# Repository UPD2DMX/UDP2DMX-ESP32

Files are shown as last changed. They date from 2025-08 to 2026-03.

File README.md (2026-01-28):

# 🌐 UDP2DMX Gateway (ESP32)



A lightweight and flexible UDP-to-DMX gateway based on the ESP32 platform, designed to bridge the **Loxone Home Automation System** with **DMX512-based lighting systems** via UDP over Wi-Fi.

This project enables direct communication between Loxone and DMX devices using a well-defined, lightweight UDP protocol. It is ideal for smart home installations where wireless DMX control is required.

---

## ⚙️ Key Features

- ✅ Based on the open-source [ESP-DMX library](https://github.com/someweisguy/esp_dmx)  
- ✅ UDP-based protocol (compatible with Loxone UDP protocol)  
- ✅ Easily testable via Jupyter notebook  

---

## 🚀 Getting Started

### 1. Install ESP-IDF

Make sure ESP-IDF **v5.0** is installed and properly set up. For installation instructions, refer to the [official ESP-IDF documentation](https://docs.espressif.com/projects/esp-idf/en/latest/esp32/get-started/index.html).

---

### 2. Clone the Repository

```bash
git clone "link to this Repo"
cd udp2dmx-esp32
```

---

### 3. Configure Project with `menuconfig`

Launch the ESP-IDF configuration menu:

```bash
idf.py menuconfig
```

Set the following options:

- 📶 **Component config → Wi-Fi Configuration**  
  - SSID and password for up to 3 different Wi-Fi networks
  - GPIO pin for network selection button (default: GPIO 0)

---

### 4. Advanced Configuration via REST API

After the device is running, you can configure advanced settings via the built-in REST API:

#### 📋 Configuration File Structure

The device uses a `config.json` file stored in SPIFFS with the following structure:

```json
{
    "hostname": "udp2dmx2",
    "ct_config": {
        "1": 2700,
        "2": 6500,
        "5": 3000
    },
    "default_ct": {
        "min": 3400,
        "max": 6600
    }
}
```

#### 🌐 REST API Endpoints

| Method  | Endpoint | Description |
| --- | --- | --- |
| `GET` | `/config` | Retrieve current configuration |
| `POST`  | `/config` | Replace entire configuration |
| `PATCH` | `/config/patch` | Update specific configuration values |

#### 📝 Configuration Options

- **`hostname`**: Device hostname for network identification
- **`ct_config`**: Color temperature mapping for specific channels (channel → Kelvin)
- **`default_ct`**: Default color temperature range for DMXL commands
  - `min`: Minimum color temperature in Kelvin
  - `max`: Maximum color temperature in Kelvin

#### 💡 Example Usage

```bash
# Get current configuration
curl http://192.168.1.100/config

# Update hostname
curl -X PATCH http://192.168.1.100/config/patch \
  -H "Content-Type: application/json" \
  -d '{"hostname": "my-dmx-gateway"}'

# Set color temperature for channel 3
curl -X PATCH http://192.168.1.100/config/patch \
  -H "Content-Type: application/json" \
  -d '{"ct_config": {"3": 4000}}'
```

---

### 5. Build and Flash Firmware

```bash
idf.py build
idf.py flash
idf.py spiffs-flash
```

---

### 6. Monitor Output
*Optional*

```bash
idf.py monitor
```

After flashing, the device will connect to Wi-Fi and output its IP address via serial console. Note this IP for testing.

---

## 🧪 DMX Communication Test
*Optional*

You can use the included **`testudp.ipynb`** Jupyter Notebook to send test UDP commands:

1. Open the notebook in Jupyter
2. Set the IP address of your ESP32 device
3. Send UDP packets to test DMX channels
4. Watch serial monitor logs or connected DMX lights to verify output

💡 **Tip**: The status LED (if configured) will blink to confirm incoming UDP traffic.

---

## 🏠 Loxone Integration

To use the gateway in your **Loxone Config**:

1. Use **Virtual Outputs** to send UDP commands to the ESP32's IP.
2. Format the command according to the protocol (see below).
3. Configure each DMX channel or RGB output as needed.

---

## 📡 UDP Protocol Overview

The device expects UDP packets in the following formats:

| Type  | Format | Description |
| ----- | --- | --- |
| **P** | `DMXP<ch>#<percent>#<fade>` | Set a single channel to a value from 0–100% with optional fade (converted to 0–255 internally). |
| **C** | `DMXC<ch>#<value>#<fade>` | Set a single channel (0–255) with optional fade time. |
| **R** | `DMXR<ch>#<rgb>#<fade>` | Set 3 consecutive channels for RGB values. Format: `RRRGGGBBB` (e.g., `128128128`). |
| **W** | `DMXW<ch>#<wwcw>#<fade>` | Set 2 consecutive channels for Tunable White. Format: `WWWCCC` (e.g., `200050` = WW:200, CW:50). |
| **L** | `DMXL<ch>#20<brightness><CT>#<fade>` | Set brightness and color temperature. Can be used with the Lumitech type from Loxone Format: `20BBBTTTT` (e.g., `200507000` = 50% at 7000 K). |

---

## 🔆 LED Behavior – Summary

| Condition | LED Behavior | Description |
| --- | --- | --- |
| **Connected (LAN or WiFi)**<br>**No DMX error** | **Off (constantly)** | Normal operation |
| **Not connected** (LAN & WiFi) | **Slow blinking** | 500 ms on / 500 ms off |
| **DMX error active** | **Fast blinking** | 100 ms on / 100 ms off |
| **User action**<br>(e.g. Wi-Fi switch)  | **Short blinking sequence** | `n` blinks with `delay_ms` (e.g. 2× 50 ms) |
| **Connecting to LAN** | **3 short blinks** | Signals successful LAN connection |
| **Connecting to WiFi** | **2 short blinks** | Signals successful WiFi connection |
| **Receiving DMX data** | **1 short blink** | Brief signal when DMX packet is received |

---

## 📁 Project Structure

```
main/
├── include/                     # Public header files
│   ├── dmx_manager.h           # DMX hardware abstraction
│   ├── udp_protocol.h          # UDP protocol handling
│   ├── udp_server.h            # UDP server implementation
│   └── system_config.h         # System configuration
├── src/                        # Source files
│   ├── main.c                  # Application entry point
│   ├── dmx_manager.c           # DMX management & fade engine
│   ├── udp_protocol.c          # Protocol parsing & execution
│   ├── udp_server.c            # UDP server & packet handling
│   └── system_config.c         # Configuration management
└── CMakeLists.txt              # Build configuration

components/
├── my_wifi/                    # WiFi management
├── my_led/                     # LED status indication
├── my_config/                  # Configuration (CT values, hostname)
└── config_handler/             # REST API for configuration
```

---

## 📋 Requirements

- ESP32 board (e.g., ESP32 DevKitC)
- RS485 transceiver (e.g., MAX485) I am using: MAX 13487
- DMX-compatible light or fixture
- Python + Jupyter (optional, for testing)

---

## 🙏 Credits

- [ESP-DMX Library](https://github.com/someweisguy/esp_dmx) by [@someweisguy](https://github.com/someweisguy)
- **Robert Lechner** for documenting the UDP DMX protocol

---

## 💖 Support

If this project helps you, consider buying me a coffee! ☕



---

## 📃 License

MIT License — see `LICENSE` file for details.

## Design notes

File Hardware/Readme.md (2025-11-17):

# Hardware

Kicad file for the UDP2DMX board. The hardware design is not finished.

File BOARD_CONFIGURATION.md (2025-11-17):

# ESP32-Digital-GW Board Configuration

## Übersicht

Die Pin-Konfiguration des UDP2DMX-ESP32-Projekts wird jetzt über die **Menuconfig (sdkconfig)** verwaltet und nicht über den Webserver. Dies ermöglicht die Erstellung von Board-spezifischen Konfigurationsdateien.

## Hardware-Pinzuordnung (ESP32-Digital-GW)

| Funktion | GPIO Pin | Beschreibung |
|---|---|---|
| DMX TX | GPIO 17 | RS485 DI (Data In) |
| DMX RX | GPIO 16 | RS485 RO (Receive Out) |
| DMX RTS | GPIO 18 | RS485 DE (Driver Enable) |
| Debug LED | GPIO 2 | Status-LED |

## Menuconfig Optionen

Die Hardware-Pins können über `idf.py menuconfig` unter dem Menü **Hardware Configuration** konfiguriert werden:

- **DMX TX GPIO Pin** (CONFIG_DMX_TX_GPIO) - Standard: 17
- **DMX RX GPIO Pin** (CONFIG_DMX_RX_GPIO) - Standard: 16
- **DMX RTS GPIO Pin** (CONFIG_DMX_RTS_GPIO) - Standard: 18
- **DMX UART Number** (CONFIG_DMX_UART_NUM) - Standard: 2
- **DMX Baudrate** (CONFIG_DMX_BAUDRATE) - Standard: 250000
- **WiFi Switch Button GPIO** (CONFIG_WIFI_SWITCH_BUTTON_GPIO) - Standard: 0 (deaktiviert)

## Board-spezifische sdkconfig Dateien

Für verschiedene Hardware-Boards sollten Board-spezifische sdkconfig-Dateien erstellt werden:

### Verwendung

```bash
# Standard-Build mit aktueller sdkconfig
idf.py build

# Build mit ESP32-Digital-GW Konfiguration
cp sdkconfig.esp32-digital-gw sdkconfig
idf.py build
```

### Verfügbare Board-Konfigurationen

- **sdkconfig.esp32-digital-gw** - ESP32-Digital-GW Hardware
  - DMX TX: GPIO 17
  - DMX RX: GPIO 16
  - DMX RTS: GPIO 18

## Neue Board-Konfiguration erstellen

Um eine neue Board-spezifische Konfiguration zu erstellen:

1. **Menuconfig öffnen:**
   ```bash
   idf.py menuconfig
   ```

2. **Hardware Configuration anpassen:**
   - Zu `Hardware Configuration` navigieren
   - Pins für das neue Board konfigurieren

3. **Konfiguration speichern:**
   - Speichern und Menuconfig beenden

4. **Board-Datei erstellen:**
   ```bash
   cp sdkconfig sdkconfig.<board-name>
   ```

5. **In Git einbinden:**
   ```bash
   git add sdkconfig.<board-name>
   git commit -m "Add sdkconfig for <board-name>"
   ```

## Integration in system_config.c

Die Hardware-Pin-Konfiguration wird beim Kompilieren automatisch aus der sdkconfig eingebunden:

```c
#include "sdkconfig.h"

static system_config_t default_config = {
    .hardware = {
        .dmx_tx_pin = CONFIG_DMX_TX_GPIO,      // Aus sdkconfig.h
        .dmx_rx_pin = CONFIG_DMX_RX_GPIO,      // Aus sdkconfig.h
        .dmx_en_pin = CONFIG_DMX_RTS_GPIO,     // Aus sdkconfig.h
        .debug_led_gpio = 2},
    // ... weitere Konfiguration ...
};
```

## Wichtige Hinweise

- ⚠️ **Keine Web-UI Konfiguration für Pins**: Die Pins werden nicht über den Webserver konfiguriert, sondern nur über Menuconfig
- ✅ **Zur Compile-Zeit festgelegt**: Die Pin-Konfiguration wird während des Compilierens festgelegt
- ✅ **Board-Portabilität**: Board-spezifische sdkconfig-Dateien ermöglichen einfaches Wechseln zwischen verschiedenen Hardware-Konfigurationen

## Webserver-Konfiguration

Der Webserver (`http://192.168.4.1` oder `http://udp2dmx.local` `http://[hostname].local`) verwaltet weiterhin:
- WiFi-Einstellungen (Netzwerkname und Passwort)
- Netzwerk-Konfiguration (IP, DHCP, DNS)
- DMX-Inhalte (via UDP-Protokoll)

Die Hardware-Pins werden **nicht** über den Webserver konfiguriert.

## Debugging

Die aktuelle Hardware-Konfiguration kann in den Logs überprüft werden:

```bash
idf.py monitor
```

Die Logs zeigen die konfigurierten Pins beim Start an.

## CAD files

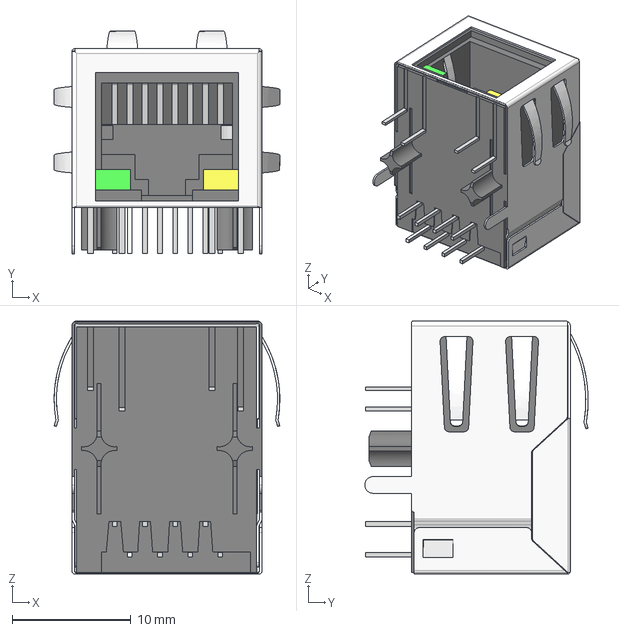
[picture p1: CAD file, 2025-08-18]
Hardware/3D/J1B1211CCD.stp
19.0 x 18.8 x 21.3 mm

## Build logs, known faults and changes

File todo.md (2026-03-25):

Webserver (manuelle Änderung der Rest API endpunkte)

- [x] lumitec testen mit Refactored code

- Menuconfig anpassen falls sinnvoll:
  - [x] DMX config 
  - [x] LED config
  - [x] Button Config
  - [x] Wifi

- [x] Webserver zur Konfiguration
- [x] Pins/RS485 Chip config über menuconfig

- [] Was ist mit den Ethernet LEDs? 

- [] OTA
- [] RS485 -2 

Muss getestet werden: 
- []Ethernet
- [x]RS485 - 1 für DMX

- github seite auf Webpage
- status auf webpage? Letzten 5 Befehle oder so fürs debugging?

# Platine
- Benötigt die Platine eine Power LED die Dauerhaft an ist? 
  - Eventuell nur einschalten wenn Knopf gedrückt? 
  - Ansonsten dunklerer LED auch in Ordnung. 

- Ethernet
  - Via USB Spannungsversorgung evtl. nicht ganz ausreichend. USB muss neu Verbunden werden damit eine sichere Netzwerkverbindung hergestellt werden kann.

- Status LED ist leicht an beim flashen. Eventuell Diode ergänzen. 
- Reset Button notwendig? 
- UART Pins auf dem Board zum flashen ohne USB? Ist USB notwendig? 

# PinOut ESP
ESP32 Wroom 32UE - 4 Mb flash
- Status LED
  - 5
- BTN0
  - 16
- RS485 - ADM 3485JRZ
  - 1
    - DI (TX): 33
    - RO (RX): 32
    - RE/DE: 13
  - 2
    - DI (TX): 12
    - RO (RX): 14
    - RE/DE: 15

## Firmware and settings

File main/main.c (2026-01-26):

#include <string.h>
#include <stdlib.h>
#include <stdio.h>
#include <math.h>

#include "freertos/FreeRTOS.h"
#include "freertos/task.h"
#include "freertos/semphr.h"
#include "esp_log.h"
#include "esp_event.h"
#include "nvs_flash.h"
#include "esp_netif.h"
// #include "protocol_examples_common.h"
#include "lwip/sockets.h"
#include "esp_dmx.h"
#include "driver/gpio.h"

#include "my_wifi.h"
#include "my_led.h"
#include "my_config.h"
#include "config_handler.h"
#include "system_config.h"

#ifdef CONFIG_ENABLE_ETHERNET
#include "my_ethernet.h"
#endif

#define DMX_UNIVERSE_SIZE DMX_PACKET_SIZE
#define UDP_PORT 6454
#define FADE_INTERVAL_MS 10
#define MAX_UDP_BUFFER_SIZE 1024

// Command result types for better error handling
typedef enum
{
    CMD_SUCCESS,
    CMD_ERROR_INVALID_CHANNEL,
    CMD_ERROR_INVALID_VALUE,
    CMD_ERROR_CONFIG_MISSING,
    CMD_ERROR_MEMORY
} command_result_t;

static const char *TAG = "udp_dmx";
static uint8_t dmx_data[DMX_UNIVERSE_SIZE] = {};
static dmx_port_t dmx_num = DMX_NUM_1;
static SemaphoreHandle_t dmx_mutex = NULL;

typedef struct
{
    bool active;
    int start_value;
    int target_value;
    int duration_ms;
    TickType_t start_time;
} fade_state_t;

static fade_state_t fade_states[DMX_UNIVERSE_SIZE] = {};

// Bounds checking function for channel validation
static bool is_channel_valid(int ch, int count)
{
    return (ch >= 1 && ch <= DMX_UNIVERSE_SIZE - count);
}

// Safe bounds checking for array access
static bool is_array_index_valid(int index)
{
    return (index >= 0 && index < DMX_UNIVERSE_SIZE);
}

// Convert speed_S to milliseconds (Using Loxone protocol)
static int speed_to_ms(int speed)
{
    if (speed == 255)
        return 0;
    if (speed >= 1 && speed <= 98)
        return speed * 591;
    if (speed >= 101 && speed <= 104)
        return (speed - 100) * 146 + 1;
    if (speed >= 201 && speed <= 254)
        return (speed - 200) * 72;
    if (speed == 254)
        return 3691;
    return 0;
}

static void stop_fade(int ch)
{
    if (!is_array_index_valid(ch))
    {
        ESP_LOGW(TAG, "Invalid channel for stop_fade: %d", ch);
        return;
    }

    if (xSemaphoreTake(dmx_mutex, pdMS_TO_TICKS(100)) == pdTRUE)
    {
        fade_states[ch].active = false;
        xSemaphoreGive(dmx_mutex);
    }
    else
    {
        ESP_LOGW(TAG, "Failed to acquire mutex in stop_fade");
    }
}

static void start_fade(int ch, int value, int duration_ms)
{
    if (!is_array_index_valid(ch))
    {
        ESP_LOGW(TAG, "Invalid channel for start_fade: %d", ch);
        return;
    }

    // Clamp value to valid range
    value = (value < 0) ? 0 : (value > 255) ? 255
                                            : value;

    if (xSemaphoreTake(dmx_mutex, pdMS_TO_TICKS(100)) == pdTRUE)
    {
        fade_states[ch].start_value = dmx_data[ch];
        fade_states[ch].target_value = value;
        fade_states[ch].duration_ms = duration_ms;
        fade_states[ch].start_time = xTaskGetTickCount();
        fade_states[ch].active = true;
        xSemaphoreGive(dmx_mutex);
    }
    else
    {
        ESP_LOGW(TAG, "Failed to acquire mutex in start_fade");
    }
}

static void fade_task(void *arg)
{
    while (1)
    {
        TickType_t now = xTaskGetTickCount();
        bool updated = false;

        if (xSemaphoreTake(dmx_mutex, pdMS_TO_TICKS(100)) == pdTRUE)
        {
            for (int ch = 0; ch < DMX_UNIVERSE_SIZE; ++ch)
            {
                if (!fade_states[ch].active)
                    continue;

                int elapsed = (now - fade_states[ch].start_time) * portTICK_PERIOD_MS;
                int duration = fade_states[ch].duration_ms;

                if (duration <= 0)
                {
                    dmx_data[ch] = fade_states[ch].target_value;
                    fade_states[ch].active = false; // Use direct access since we have mutex
                    updated = true;
                    continue;
                }

                int start = fade_states[ch].start_value;
                int target = fade_states[ch].target_value;

                uint8_t new_value;

                if (elapsed >= duration)
                {
                    new_value = target;
                    fade_states[ch].active = false; // Use direct access since we have mutex
                }
                else
                {
                    float t = (float)elapsed / (float)duration;
                    float interpolated = start + (target - start) * t;
                    new_value = (uint8_t)roundf(interpolated);
                }

                if (dmx_data[ch] != new_value)
                {
                    dmx_data[ch] = new_value;
                    updated = true;
                }
            }

            if (updated)
            {
                esp_err_t err = dmx_write(dmx_num, dmx_data, DMX_UNIVERSE_SIZE);
                if (err != ESP_OK)
                {
                    ESP_LOGW(TAG, "DMX write failed: %s", esp_err_to_name(err));
                }
            }

            xSemaphoreGive(dmx_mutex);
        }
        else
        {
            ESP_LOGW(TAG, "Failed to acquire mutex in fade_task");
        }

        vTaskDelay(pdMS_TO_TICKS(FADE_INTERVAL_MS));
    }
}

static command_result_t set_channel(int ch, int value, int fade_ms)
{
    if (!is_channel_valid(ch, 1))
    {
        ESP_LOGW(TAG, "Invalid channel: %d", ch);
        return CMD_ERROR_INVALID_CHANNEL;
    }

    // Clamp value to valid range
    value = (value < 0) ? 0 : (value > 255) ? 255
                                            : value;

    if (fade_ms > 0 && dmx_data[ch] != value)
    {
        start_fade(ch, value, fade_ms);
    }
    else
    {
        stop_fade(ch);
        if (xSemaphoreTake(dmx_mutex, pdMS_TO_TICKS(100)) == pdTRUE)
        {
            dmx_data[ch] = value;
            esp_err_t err = dmx_write(dmx_num, dmx_data, DMX_UNIVERSE_SIZE);
            if (err != ESP_OK)
            {
                ESP_LOGW(TAG, "DMX write failed: %s", esp_err_to_name(err));
            }
            xSemaphoreGive(dmx_mutex);
        }
        else
        {
            ESP_LOGW(TAG, "Failed to acquire mutex in set_channel");
            return CMD_ERROR_MEMORY;
        }
    }
    return CMD_SUCCESS;
}

static command_result_t set_multi_channels(int ch, int *values, int count, int fade_ms)
{
    if (!is_channel_valid(ch, count))
    {
        ESP_LOGW(TAG, "Invalid channel range: %d-%d", ch, ch + count - 1);
        return CMD_ERROR_INVALID_CHANNEL;
    }

    if (!values)
    {
        ESP_LOGW(TAG, "NULL values pointer in set_multi_channels");
        return CMD_ERROR_INVALID_VALUE;
    }

    if (fade_ms > 0)
    {
        for (int i = 0; i < count; ++i)
        {
            // Clamp values to valid range
            int clamped_value = (values[i] < 0) ? 0 : (values[i] > 255) ? 255
                                                                        : values[i];
            start_fade(ch + i, clamped_value, fade_ms);
        }
    }
    else
    {
        if (xSemaphoreTake(dmx_mutex, pdMS_TO_TICKS(100)) == pdTRUE)
        {
            for (int i = 0; i < count; ++i)
            {
                fade_states[ch + i].active = false; // Direct access since we have mutex
                // Clamp values to valid range
                int clamped_value = (values[i] < 0) ? 0 : (values[i] > 255) ? 255
                                                                            : values[i];
                dmx_data[ch + i] = clamped_value;
            }
            esp_err_t err = dmx_write(dmx_num, dmx_data, DMX_UNIVERSE_SIZE);
            if (err != ESP_OK)
            {
                ESP_LOGW(TAG, "DMX write failed: %s", esp_err_to_name(err));
            }
            xSemaphoreGive(dmx_mutex);
        }
        else
        {
            ESP_LOGW(TAG, "Failed to acquire mutex in set_multi_channels");
            return CMD_ERROR_MEMORY;
        }
    }
    return CMD_SUCCESS;
}
// Command parsing with validation
typedef struct
{
    char mode;
    int channel;
    int value;
    int speed;
    bool valid;
} parsed_command_t;

static parsed_command_t parse_udp_command(const char *cmd)
{
    parsed_command_t result = {0};

    if (!cmd || strlen(cmd) < 4)
    {
        ESP_LOGW(TAG, "Command too short or NULL");
        return result;
    }

    if (strncmp(cmd, "DMX", 3) != 0)
    {
        ESP_LOGW(TAG, "Command doesn't start with DMX");
        return result;
    }

    char *copy = strdup(cmd);
    if (!copy)
    {
        ESP_LOGE(TAG, "Memory allocation failed");
        return result;
    }

    char *type = strtok(copy + 3, "#");
    char *arg1 = strtok(NULL, "#");
    char *arg2 = strtok(NULL, "#");

    if (!type || !arg1)
    {
        ESP_LOGW(TAG, "Missing required arguments in command: %s", cmd);
        free(copy);
        return result;
    }

    result.mode = type[0];
    result.channel = atoi(type + 1);
    result.value = atoi(arg1);
    result.speed = arg2 ? atoi(arg2) : 255;
    result.valid = true;

    free(copy);
    return result;
}

static command_result_t handle_udp_command(const char *cmd)
{
    static command_result_t handle_udp_command(const char *cmd)
    {
        parsed_command_t parsed = parse_udp_command(cmd);

        if (!parsed.valid)
        {
            return CMD_ERROR_INVALID_VALUE;
        }

        int ch = parsed.channel;
        int val = parsed.value;
        int fade_ms = speed_to_ms(parsed.speed);
        char mode = parsed.mode;

        // Basic channel validation for commands that need multiple channels
        if ((mode == 'L' || mode == 'W') && !is_channel_valid(ch, 2))
        {
            ESP_LOGW(TAG, "Invalid channel for %c command: %d", mode, ch);
            return CMD_ERROR_INVALID_CHANNEL;
        }
        if (mode == 'R' && !is_channel_valid(ch, 3))
        {
            ESP_LOGW(TAG, "Invalid channel for RGB command: %d", ch);
            return CMD_ERROR_INVALID_CHANNEL;
        }
        if ((mode == 'C' || mode == 'P') && !is_channel_valid(ch, 1))
        {
            ESP_LOGW(TAG, "Invalid channel for %c command: %d", mode, ch);
            return CMD_ERROR_INVALID_CHANNEL;
        }

        command_result_t result = CMD_SUCCESS;

        switch (mode)
        {
        case 'R':
        {
            // Validate RGB values are in reasonable range
            if (val < 0 || val > 999999999)
            {
                ESP_LOGW(TAG, "RGB value out of range: %d", val);
                return CMD_ERROR_INVALID_VALUE;
            }

            int r = (val % 1000);
            int g = ((val / 1000) % 1000);
            int b = ((val / 1000000) % 1000);

            // Clamp RGB values to 0-255 range
            r = (r > 255) ? 255 : r;
            g = (g > 255) ? 255 : g;
            b = (b > 255) ? 255 : b;

            int rgb[3] = {r, g, b};
            result = set_multi_channels(ch, rgb, 3, fade_ms);

            if (result == CMD_SUCCESS)
            {
                ESP_LOGI(TAG, "RGB %d: R=%d G=%d B=%d mit Fading %d ms", ch, r, g, b, fade_ms);
            }
            break;
        }
        case 'W':
        {
            int ww = (val / 1000) % 1000;
            int cw = val % 1000;

            ww = ww > 255 ? 255 : (ww < 0 ? 0 : ww);
            cw = cw > 255 ? 255 : (cw < 0 ? 0 : cw);

            int tw[2] = {ww, cw};
            result = set_multi_channels(ch, tw, 2, fade_ms);

            if (result == CMD_SUCCESS)
            {
                ESP_LOGI(TAG, "TW %d: WW=%d CW=%d with fading %d ms", ch, ww, cw, fade_ms);
            }
            break;
        }
        case 'L':
        {
            if (val < 200000000 || val > 209999999)
            {
                ESP_LOGW(TAG, "Invalid Lumitec-Command: %d", val);
                return CMD_ERROR_INVALID_VALUE;
            }

            // 1) Extract target brightness (0–100) and target CT (e.g. 2700…6500)
            int brightness = (val / 10000) % 1000;
            int color_temp = val % 10000;

            brightness = brightness < 0 ? 0 : (brightness > 100 ? 100 : brightness);

            // 2) Sort WW/CW by actual CT
            int ct_ww, ct_cw, ch_ww, ch_cw;
            get_ct_sorted(ch, &ct_ww, &ct_cw, &ch_ww, &ch_cw);

            // 3) Soll-CT auf erlaubten Bereich clampen
            if (color_temp < ct_ww)
                color_temp = ct_ww;
            if (color_temp > ct_cw)
                color_temp = ct_cw;

            // 4) Decision: which channel gets how much?
            int val_ww = 0, val_cw = 0;
            int value = brightness * 255 / 100;

            if (color_temp <= ct_ww + 100)
            {
                // fast ganz warm → nur WW an
                val_ww = value;
                val_cw = 0;
            }
            else if (color_temp >= ct_cw - 100)
            {
                // fast ganz kalt → nur CW an
                val_ww = 0;
                val_cw = value;
            }
            else
            {
                // Mischfarbe → normal berechnen
                int range = ct_cw - ct_ww;
                if (range <= 0)
                {
                    ESP_LOGW(TAG, "Invalid CT range for channel %d", ch);
                    return CMD_ERROR_CONFIG_MISSING;
                }

                long num_cw = (long)brightness * (color_temp - ct_ww) * 255;
                long num_ww = (long)brightness * (ct_cw - color_temp) * 255;
                long den = (long)range * 100;

                val_cw = (int)((num_cw + den / 2) / den);
                val_ww = (int)((num_ww + den / 2) / den);

                if (val_cw * 100 / 255 < 2)
                    val_cw = 0;
                if (val_ww * 100 / 255 < 2)
                    val_ww = 0;
            }

            // 5) Array für set_multi_channels aufbauen
            int start_ch = (ch_ww < ch_cw ? ch_ww : ch_cw);
            int values[2] = {0, 0};
            values[ch_ww - start_ch] = val_ww;
            values[ch_cw - start_ch] = val_cw;

            // 6) abschicken
            result = set_multi_channels(start_ch, values, 2, fade_ms);

            if (result == CMD_SUCCESS)
            {
                ESP_LOGI(TAG, "Lichtfarbe %dK, Helligkeit %d%% → WW=%d (CH%d), CW=%d (CH%d)",
                         color_temp, brightness, val_ww, ch_ww, val_cw, ch_cw);
            }
            break;
        }

        case 'P':
            val = (val * 255) / 100;
            // Clamp percentage to valid range
            val = (val < 0) ? 0 : (val > 255) ? 255
                                              : val;
            __attribute__((fallthrough));
        case 'C':
            result = set_channel(ch, val, fade_ms);
            if (result == CMD_SUCCESS)
            {
                ESP_LOGI(TAG, "Channel %d set to %d", ch, val);
            }
            break;
        default:
            ESP_LOGW(TAG, "Unbekannter Modus: %c", mode);
            return CMD_ERROR_INVALID_VALUE;
        }

        return result;
    }
}

void udp_server_task(void *arg)
{
    int sock = socket(AF_INET, SOCK_DGRAM, IPPROTO_IP);
    if (sock < 0)
    {
        ESP_LOGE(TAG, "UDP socket creation failed: errno %d", errno);
        vTaskDelete(NULL);
        return;
    }

    struct sockaddr_in bind_addr = {
        .sin_family = AF_INET,
        .sin_port = htons(UDP_PORT),
        .sin_addr.s_addr = htonl(INADDR_ANY)};

    if (bind(sock, (struct sockaddr *)&bind_addr, sizeof(bind_addr)) < 0)
    {
        ESP_LOGE(TAG, "UDP socket bind failed: errno %d", errno);
        close(sock);
        vTaskDelete(NULL);
        return;
    }

    char rx_buffer[MAX_UDP_BUFFER_SIZE];
    struct sockaddr_in6 source_addr;
    socklen_t socklen = sizeof(source_addr);

    ESP_LOGI(TAG, "UDP server started on port %d", UDP_PORT);

    while (1)
    {
        int len = recvfrom(sock, rx_buffer, sizeof(rx_buffer) - 1, 0,
                           (struct sockaddr *)&source_addr, &socklen);

        if (len < 0)
        {
            ESP_LOGW(TAG, "UDP recvfrom failed: errno %d", errno);
            continue;
        }

        ESP_LOGD(TAG, "UDP empfangen, Länge = %d", len);

        if (len == DMX_UNIVERSE_SIZE)
        {
            // Full DMX universe data
            if (xSemaphoreTake(dmx_mutex, pdMS_TO_TICKS(100)) == pdTRUE)
            {
                memcpy(dmx_data, rx_buffer, DMX_UNIVERSE_SIZE);
                for (int i = 0; i < DMX_UNIVERSE_SIZE; ++i)
                    fade_states[i].active = false;

                esp_err_t err = dmx_write(dmx_num, dmx_data, DMX_UNIVERSE_SIZE);
                if (err != ESP_OK)
                {
                    ESP_LOGW(TAG, "DMX write failed: %s", esp_err_to_name(err));
                }
                xSemaphoreGive(dmx_mutex);
            }
            else
            {
                ESP_LOGW(TAG, "Failed to acquire mutex for DMX universe update");
            }
        }
        else if (len > 4 && len < MAX_UDP_BUFFER_SIZE && strncmp(rx_buffer, "DMX", 3) == 0)
        {
            rx_buffer[len] = '\0';
            ESP_LOGI(TAG, "DMX-Befehl empfangen: \"%s\"", rx_buffer);
            my_led_blink(1, 20);

            command_result_t result = handle_udp_command(rx_buffer);
            if (result != CMD_SUCCESS)
            {
                ESP_LOGW(TAG, "Command execution failed with result: %d", result);
            }
        }
        else
        {
            ESP_LOGW(TAG, "Invalid UDP packet received, length: %d", len);
        }
    }

    close(sock);
}

void app_main()
{
    esp_log_level_set("wifi", ESP_LOG_DEBUG);
    esp_log_level_set("event", ESP_LOG_DEBUG);
    ESP_ERROR_CHECK(nvs_flash_init());
    ESP_ERROR_CHECK(esp_netif_init());
    ESP_ERROR_CHECK(esp_event_loop_create_default());

    // Initialize mutex for thread-safe DMX operations
    dmx_mutex = xSemaphoreCreateMutex();
    if (dmx_mutex == NULL)
    {
        ESP_LOGE(TAG, "Failed to create DMX mutex");
        return;
    }

    // Initialize system configuration
    esp_err_t err = system_config_init();
    if (err != ESP_OK)
    {
        ESP_LOGE(TAG, "Failed to initialize system config: %s", esp_err_to_name(err));
        return;
    }

    const system_config_t *sys_config = system_config_get();
    system_config_print(sys_config);

    my_led_init(sys_config->hardware.debug_led_gpio);

    // Network initialization - prefer Ethernet over WiFi
    bool network_ready = false;

#ifdef CONFIG_ENABLE_ETHERNET
    if (sys_config->ethernet.enable)
    {
        ESP_LOGI(TAG, "Initializing Ethernet...");
        err = my_ethernet_init(
            sys_config->ethernet.mdc_gpio,
            sys_config->ethernet.mdio_gpio,
            sys_config->ethernet.phy_addr,
            sys_config->ethernet.phy_power_gpio,
            sys_config->ethernet.phy_rst_gpio,
            sys_config->ethernet.clock_mode,
            "udp2dmx-eth");

        if (err == ESP_OK)
        {
            err = my_ethernet_start();
            if (err == ESP_OK)
            {
                ESP_LOGI(TAG, "Ethernet started successfully");
                // Wait a bit for Ethernet to connect
                vTaskDelay(pdMS_TO_TICKS(3000));
                
                if (my_ethernet_is_connected())
                {
                    char ip_str[16];
                    if (my_ethernet_get_ip(ip_str))
                    {
                        ESP_LOGI(TAG, "Ethernet connected with IP: %s", ip_str);
                        network_ready = true;
                    }
                }
                else
                {
                    ESP_LOGW(TAG, "Ethernet link not established; will fall back to WiFi");
                }
            }
            else
            {
                ESP_LOGW(TAG, "Failed to start Ethernet: %s", esp_err_to_name(err));
            }
        }
        else
        {
            ESP_LOGW(TAG, "Failed to initialize Ethernet: %s", esp_err_to_name(err));
        }
    }
#endif

    // Start WiFi only if Ethernet is not connected
    if (!network_ready)
    {
        ESP_LOGI(TAG, "Starting WiFi (Ethernet not connected)...");
        my_wifi_init();
        network_ready = true;
    }
    else
    {
        ESP_LOGI(TAG, "Ethernet active - WiFi skipped");
    }

    // DMX Setup
    dmx_config_t config = DMX_CONFIG_DEFAULT;
    err = dmx_driver_install(dmx_num, &config, NULL, 0);
    if (err != ESP_OK)
    {
        ESP_LOGE(TAG, "DMX driver install failed: %s", esp_err_to_name(err));
        return;
    }

    err = dmx_set_pin(dmx_num, sys_config->hardware.dmx_tx_pin, sys_config->hardware.dmx_rx_pin, sys_config->hardware.dmx_en_pin);
    if (err != ESP_OK)
    {
        ESP_LOGE(TAG, "DMX pin setup failed: %s", esp_err_to_name(err));
        return;
    }

    memset(dmx_data, 0, sizeof(dmx_data));
    err = dmx_write(dmx_num, dmx_data, DMX_UNIVERSE_SIZE);
    if (err != ESP_OK)
    {
        ESP_LOGW(TAG, "Initial DMX write failed: %s", esp_err_to_name(err));
    }

    // Tasks starten
    BaseType_t task_result;
    task_result = xTaskCreate(udp_server_task, "udp_server", 8192, NULL, 5, NULL);
    if (task_result != pdPASS)
    {
        ESP_LOGE(TAG, "Failed to create UDP server task");
        return;
    }

    task_result = xTaskCreate(fade_task, "fade_task", 4096, NULL, 5, NULL);
    if (task_result != pdPASS)
    {
        ESP_LOGE(TAG, "Failed to create fade task");
        return;
    }

    ESP_LOGI(TAG, "System bereit: DMX aktiv & WiFi verbunden");
    my_led_blink(2, 200);

    spiffs_init();
    config_load_from_spiffs("/spiffs/config.json");
    start_rest_server();

    TickType_t last = xTaskGetTickCount();
    while (1)
    {
        err = dmx_send(dmx_num);
        if (err != ESP_OK)
        {
            ESP_LOGW(TAG, "DMX send failed: %s", esp_err_to_name(err));
        }
        vTaskDelayUntil(&last, pdMS_TO_TICKS(30));
    }
}

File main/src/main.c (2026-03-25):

#include <string.h>
#include <stdlib.h>
#include <stdio.h>

#include "esp_log.h"
#include "esp_event.h"
#include "nvs_flash.h"
#include "esp_netif.h"

// System modules
#include "system_config.h"
#include "dmx_manager.h"
#include "udp_server.h"
#include "udp_protocol.h"

// Component modules
#include "my_wifi.h"
#include "my_led.h"
#include "my_config.h"
#include "config_handler.h"

#ifdef CONFIG_ENABLE_ETHERNET
#include "my_ethernet.h"
#endif

static const char *TAG = "main";

// System initialization functions
static esp_err_t init_system_base(void);
static esp_err_t init_system_components(void);
static esp_err_t init_dmx_system(void);
static esp_err_t init_network_services(void);
static esp_err_t start_main_loop(void);

void app_main()
{
    ESP_LOGI(TAG, "=== UDP2DMX Gateway Starting ===");

    // Initialize system base
    esp_err_t err = init_system_base();
    if (err != ESP_OK) {
        ESP_LOGE(TAG, "Failed to initialize system base: %s", esp_err_to_name(err));
        return;
    }

    // Initialize system components
    err = init_system_components();
    if (err != ESP_OK) {
        ESP_LOGE(TAG, "Failed to initialize system components: %s", esp_err_to_name(err));
        return;
    }

    // Initialize network services first (like in working version)
    err = init_network_services();
    if (err != ESP_OK) {
        ESP_LOGE(TAG, "Failed to initialize network services: %s", esp_err_to_name(err));
        return;
    }

    // Initialize DMX system AFTER WiFi (like in working version)
    err = init_dmx_system();
    if (err != ESP_OK) {
        ESP_LOGE(TAG, "Failed to initialize DMX system: %s", esp_err_to_name(err));
        return;
    }

    ESP_LOGI(TAG, "=== System initialization complete ===");
    
    // Start main loop
    start_main_loop();
}

static esp_err_t init_system_base(void)
{
    ESP_LOGI(TAG, "Initializing system base...");

    // Set log levels
    esp_log_level_set("wifi", ESP_LOG_DEBUG);
    esp_log_level_set("event", ESP_LOG_DEBUG);

    // Initialize NVS
    esp_err_t err = nvs_flash_init();
    if (err != ESP_OK) {
        ESP_LOGE(TAG, "NVS flash init failed: %s", esp_err_to_name(err));
        return err;
    }

    // Initialize network interface
    err = esp_netif_init();
    if (err != ESP_OK) {
        ESP_LOGE(TAG, "Network interface init failed: %s", esp_err_to_name(err));
        return err;
    }

    // Create default event loop
    err = esp_event_loop_create_default();
    if (err != ESP_OK) {
        ESP_LOGE(TAG, "Event loop creation failed: %s", esp_err_to_name(err));
        return err;
    }

    // Initialize system configuration
    err = system_config_init();
    if (err != ESP_OK) {
        ESP_LOGE(TAG, "System config init failed: %s", esp_err_to_name(err));
        return err;
    }

    // Print system configuration
    system_config_print(system_config_get());

    return ESP_OK;
}

static esp_err_t init_system_components(void)
{
    ESP_LOGI(TAG, "Initializing system components...");
    
    const system_config_t *config = system_config_get();

    // Initialize LED
    my_led_init(config->hardware.debug_led_gpio);

    // Initialize SPIFFS first to load hostname later
    spiffs_init();

    // Try Ethernet first (if enabled)
    bool network_ready = false;
    
#ifdef CONFIG_ENABLE_ETHERNET
    if (config->ethernet.enable)
    {
        ESP_LOGI(TAG, "Initializing Ethernet...");
        esp_err_t err = my_ethernet_init(
            config->ethernet.mdc_gpio,
            config->ethernet.mdio_gpio,
            config->ethernet.phy_addr,
            config->ethernet.phy_power_gpio,
            config->ethernet.phy_rst_gpio,
            config->ethernet.clock_mode,
            "udp2dmx");  // Use default, will be updated after config load

        if (err == ESP_OK)
        {
            err = my_ethernet_start();
            if (err == ESP_OK)
            {
                ESP_LOGI(TAG, "Ethernet started successfully");
                // Wait a bit for Ethernet to connect
                vTaskDelay(pdMS_TO_TICKS(3000));
                
                if (my_ethernet_is_connected())
                {
                    char ip_str[16];
                    if (my_ethernet_get_ip(ip_str))
                    {
                        ESP_LOGI(TAG, "Ethernet connected with IP: %s", ip_str);
                        network_ready = true;
                    }
                }
                else
                {
                    ESP_LOGW(TAG, "Ethernet link not established; will fall back to WiFi");
                }
            }
            else
            {
                ESP_LOGW(TAG, "Failed to start Ethernet: %s", esp_err_to_name(err));
            }
        }
        else
        {
            ESP_LOGW(TAG, "Failed to initialize Ethernet: %s", esp_err_to_name(err));
        }
    }
#endif

    // Initialize WiFi only if Ethernet is not connected
    if (!network_ready)
    {
        ESP_LOGI(TAG, "Starting WiFi (Ethernet not available or not connected)...");
        my_wifi_init();
    }
    else
    {
        ESP_LOGI(TAG, "Network ready via Ethernet, skipping WiFi initialization");
    }

    // Load configuration from SPIFFS (hostname will be set via my_wifi_set_hostname)
    config_load_from_spiffs("/spiffs/config.json");

    return ESP_OK;
}

static esp_err_t init_dmx_system(void)
{
    ESP_LOGI(TAG, "Initializing DMX system...");
    
    // Wait a bit for system stability (like in working version)
    vTaskDelay(pdMS_TO_TICKS(2000));
    ESP_LOGI(TAG, "System settled, proceeding with DMX initialization");
    
    const rs485_port_config_t *active_port = system_config_get_active_dmx_port();
    if (!active_port)
    {
        ESP_LOGE(TAG, "No active RS485 output available for DMX");
        return ESP_FAIL;
    }

    ESP_LOGI(TAG, "Using RS485-%d for DMX (UART=%d TX=%d RX=%d EN=%d)",
             system_config_get_dmx_output_select(),
             active_port->uart_num,
             active_port->tx_pin,
             active_port->rx_pin,
             active_port->en_pin);

    // Initialize DMX manager
    esp_err_t err = dmx_manager_init(
        active_port->uart_num,
        active_port->tx_pin,
        active_port->rx_pin,
        active_port->en_pin
    );
    
    if (err != ESP_OK) {
        ESP_LOGE(TAG, "DMX manager initialization failed: %s", esp_err_to_name(err));
        return err;
    }

    // Initialize UDP protocol
    err = udp_protocol_init();
    if (err != ESP_OK) {
        ESP_LOGE(TAG, "UDP protocol initialization failed: %s", esp_err_to_name(err));
        return err;
    }

    return ESP_OK;
}
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

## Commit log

2025-08-18 added components
    [J1B1211CCD.stp, esp32-udp2dmx.kicad_pcb, esp32-udp2dmx.kicad_sch]
2025-08-19 update schematic
    [esp32-udp2dmx.kicad_sch]
2026-01-23 update pins for Cod.m board
